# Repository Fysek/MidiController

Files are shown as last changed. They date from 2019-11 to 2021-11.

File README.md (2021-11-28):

# MidiController

The goal of the project is to create and test an extension board with two SIPO 74HC595 shift registers.
The system will work with Arduino Uno.

The registers function is to expand the number of input and output ports of the Arduino board. The whole will work as a controller for the MIDI keyboard.

The use of shift registers allows you to use every available keyboard.

There are two version of the board: 1. Board with additional connections and LED diodes to observe input and outputs
                                    2. Board without connections and LEDs

Tests has been manually executed in NI TestStand. The board was connected via NI myRIO.

## Board without testpoints:

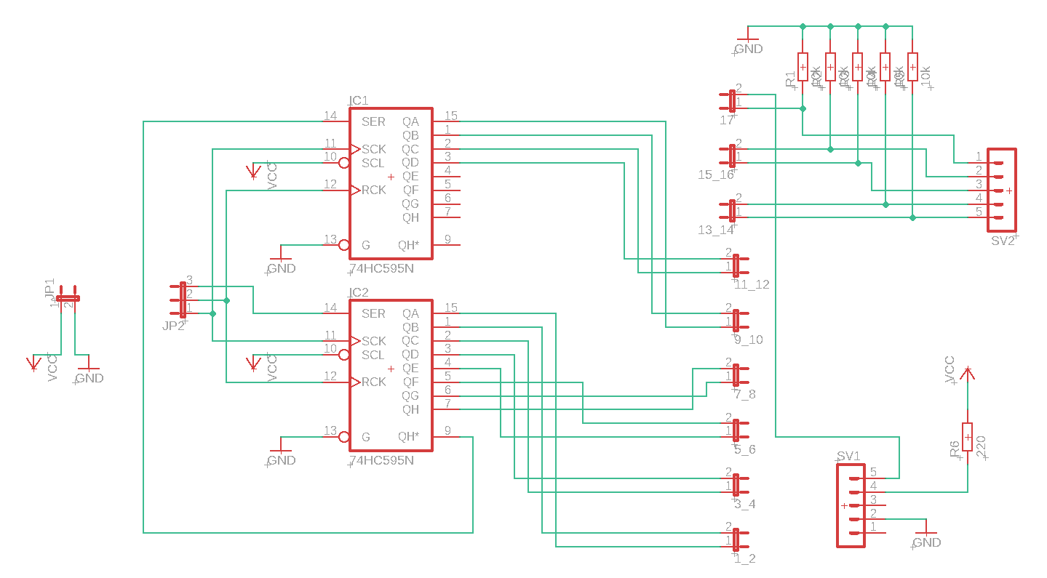
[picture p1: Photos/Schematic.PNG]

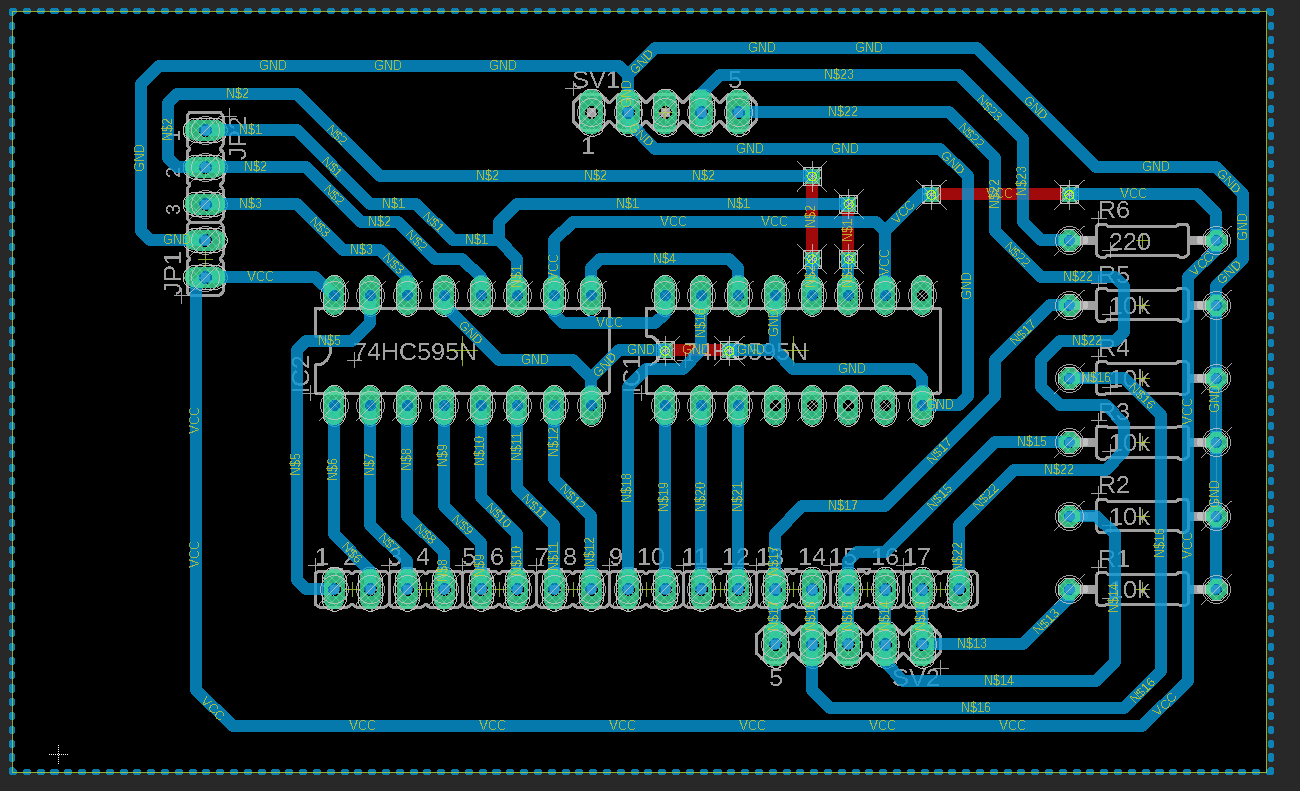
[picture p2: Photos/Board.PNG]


## Board with testpoints:
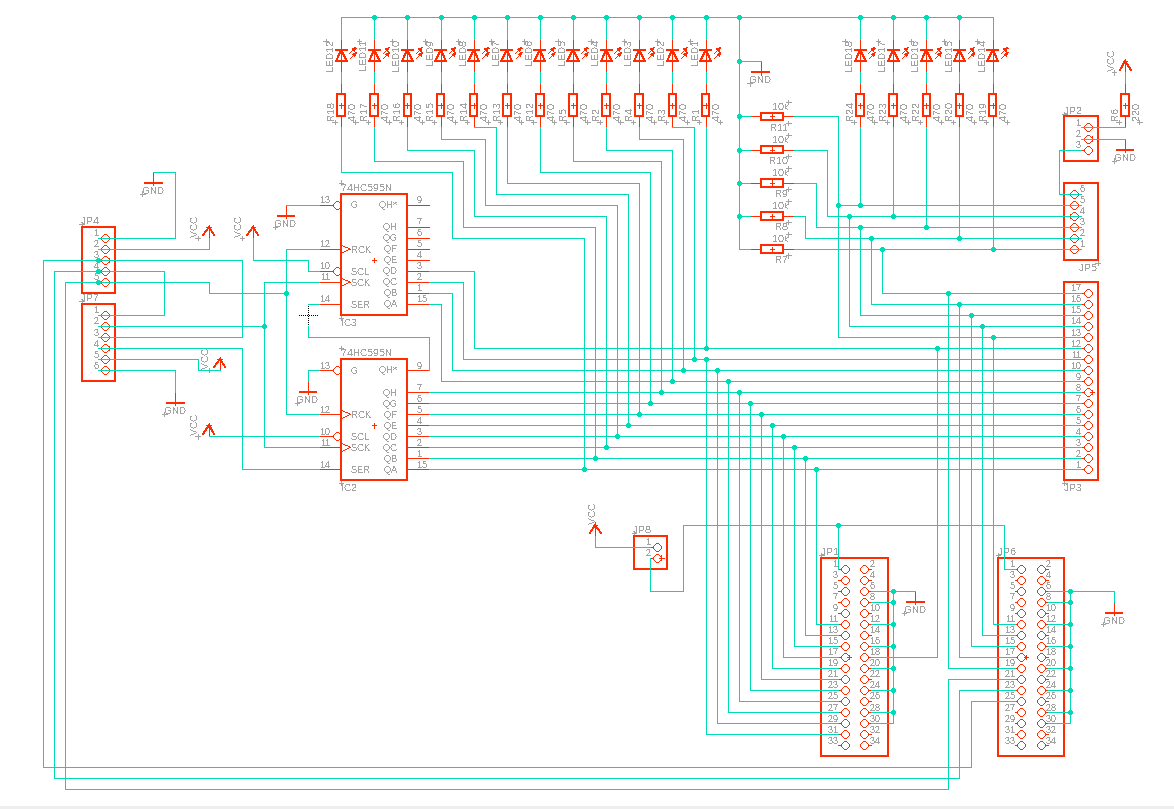
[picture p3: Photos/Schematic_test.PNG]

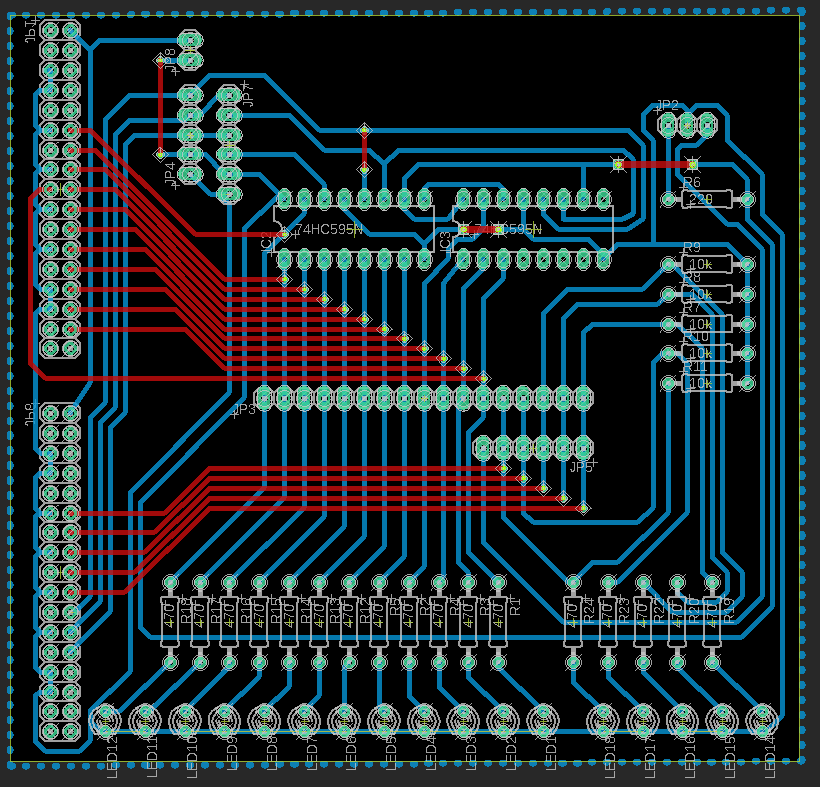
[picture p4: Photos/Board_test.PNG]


## Testing with NI myRIO:
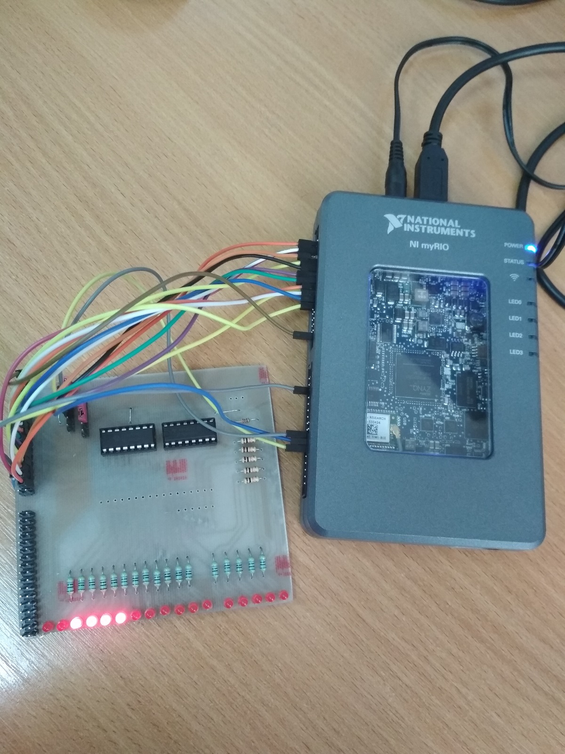
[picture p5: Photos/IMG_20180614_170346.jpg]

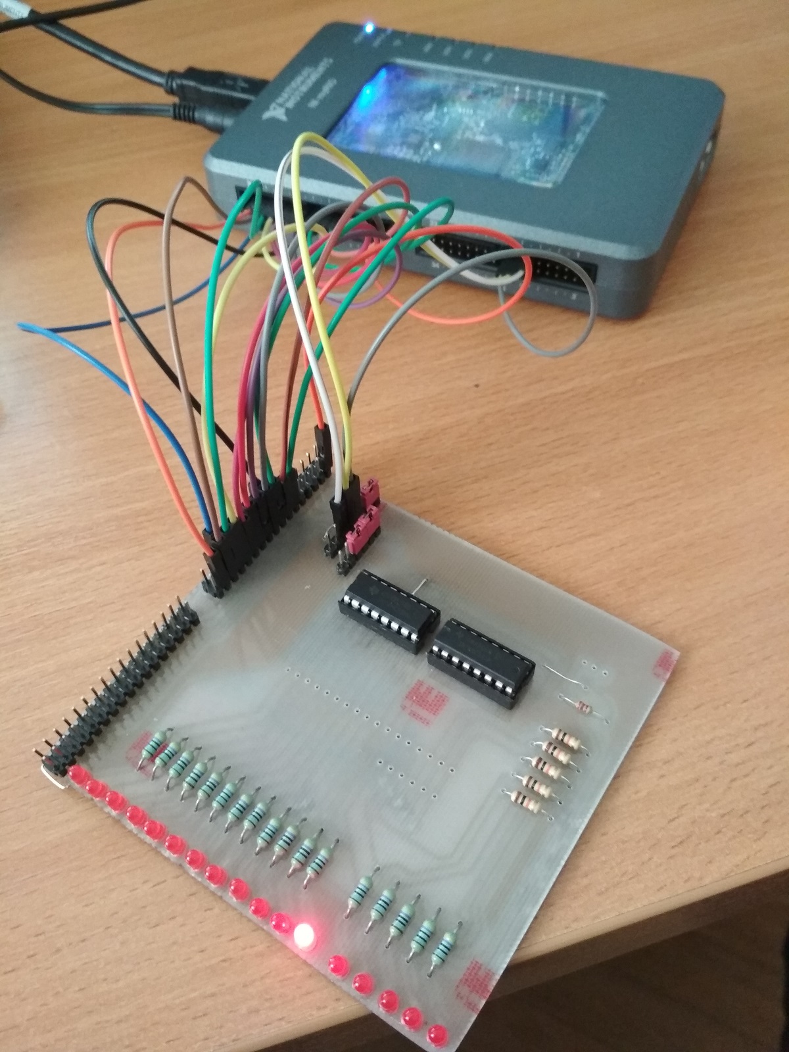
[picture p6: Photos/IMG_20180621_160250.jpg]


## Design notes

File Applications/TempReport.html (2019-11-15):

##### UUT Report

Station ID | PC07
Serial Number | 1
Date | czwartek, 21 czerwca 2018
Time | 16:03:20
Operator | administrator
Execution Time | 50.211 seconds
Number of Results | 24
UUT Result | Passed

Expand/Collapse Expand / Collapse MainSequence

Begin Sequence: MainSequence
(C:\Users\student\Documents\Dyr_Mar\shift_reg\Sequence File 1.seq)

Step | Status | Measurement | Units | Limits
| | | | Nominal Value | Low Limit | High Limit | Comparison Type
Pass/Fail Test | Passed
Parameters
data (B_DIO0 (Pin 11)): | False
latch (B_DIO2 (Pin 15)): | False
clk (B_DIO1 (Pin 13)): | False
TestResults/Data
16bit integer: | 1

Step | Status | Measurement | Units | Limits
| | | | Nominal Value | Low Limit | High Limit | Comparison Type
End(For) | Done

Step | Status | Measurement | Units | Limits
| | | | Nominal Value | Low Limit | High Limit | Comparison Type
Pass/Fail Test | Passed
Parameters
data (B_DIO0 (Pin 11)): | False
latch (B_DIO2 (Pin 15)): | False
clk (B_DIO1 (Pin 13)): | False
TestResults/Data
16bit integer: | 2

Step | Status | Measurement | Units | Limits
| | | | Nominal Value | Low Limit | High Limit | Comparison Type
End(For) | Done

Step | Status | Measurement | Units | Limits
| | | | Nominal Value | Low Limit | High Limit | Comparison Type
Pass/Fail Test | Passed
Parameters
data (B_DIO0 (Pin 11)): | False
latch (B_DIO2 (Pin 15)): | False
clk (B_DIO1 (Pin 13)): | False
TestResults/Data
16bit integer: | 4

Step | Status | Measurement | Units | Limits
| | | | Nominal Value | Low Limit | High Limit | Comparison Type
End(For) | Done

Step | Status | Measurement | Units | Limits
| | | | Nominal Value | Low Limit | High Limit | Comparison Type
Pass/Fail Test | Passed
Parameters
data (B_DIO0 (Pin 11)): | False
latch (B_DIO2 (Pin 15)): | False
clk (B_DIO1 (Pin 13)): | False
TestResults/Data
16bit integer: | 8

Step | Status | Measurement | Units | Limits
| | | | Nominal Value | Low Limit | High Limit | Comparison Type
End(For) | Done

Step | Status | Measurement | Units | Limits
| | | | Nominal Value | Low Limit | High Limit | Comparison Type
Pass/Fail Test | Passed
Parameters
data (B_DIO0 (Pin 11)): | False
latch (B_DIO2 (Pin 15)): | False
clk (B_DIO1 (Pin 13)): | False
TestResults/Data
16bit integer: | 16

Step | Status | Measurement | Units | Limits
| | | | Nominal Value | Low Limit | High Limit | Comparison Type
End(For) | Done

Step | Status | Measurement | Units | Limits
| | | | Nominal Value | Low Limit | High Limit | Comparison Type
Pass/Fail Test | Passed
Parameters
data (B_DIO0 (Pin 11)): | False
latch (B_DIO2 (Pin 15)): | False
clk (B_DIO1 (Pin 13)): | False
TestResults/Data
16bit integer: | 32

Step | Status | Measurement | Units | Limits
| | | | Nominal Value | Low Limit | High Limit | Comparison Type
End(For) | Done

Step | Status | Measurement | Units | Limits
| | | | Nominal Value | Low Limit | High Limit | Comparison Type
Pass/Fail Test | Passed
Parameters
data (B_DIO0 (Pin 11)): | False
latch (B_DIO2 (Pin 15)): | False
clk (B_DIO1 (Pin 13)): | False
TestResults/Data
16bit integer: | 64

Step | Status | Measurement | Units | Limits
| | | | Nominal Value | Low Limit | High Limit | Comparison Type
End(For) | Done

Step | Status | Measurement | Units | Limits
| | | | Nominal Value | Low Limit | High Limit | Comparison Type
Pass/Fail Test | Passed
Parameters
data (B_DIO0 (Pin 11)): | False
latch (B_DIO2 (Pin 15)): | False
clk (B_DIO1 (Pin 13)): | False
TestResults/Data
16bit integer: | 128

Step | Status | Measurement | Units | Limits
| | | | Nominal Value | Low Limit | High Limit | Comparison Type
End(For) | Done

Step | Status | Measurement | Units | Limits
| | | | Nominal Value | Low Limit | High Limit | Comparison Type
Pass/Fail Test | Passed
Parameters
data (B_DIO0 (Pin 11)): | False
latch (B_DIO2 (Pin 15)): | False
clk (B_DIO1 (Pin 13)): | False
TestResults/Data
16bit integer: | 256

Step | Status | Measurement | Units | Limits
| | | | Nominal Value | Low Limit | High Limit | Comparison Type
End(For) | Done

Step | Status | Measurement | Units | Limits
| | | | Nominal Value | Low Limit | High Limit | Comparison Type
Pass/Fail Test | Passed
Parameters
data (B_DIO0 (Pin 11)): | False
latch (B_DIO2 (Pin 15)): | False
clk (B_DIO1 (Pin 13)): | False
TestResults/Data
16bit integer: | 512

Step | Status | Measurement | Units | Limits
| | | | Nominal Value | Low Limit | High Limit | Comparison Type
End(For) | Done

Step | Status | Measurement | Units | Limits
| | | | Nominal Value | Low Limit | High Limit | Comparison Type
Pass/Fail Test | Passed
Parameters
data (B_DIO0 (Pin 11)): | False
latch (B_DIO2 (Pin 15)): | False
clk (B_DIO1 (Pin 13)): | False
TestResults/Data
16bit integer: | 1024

Step | Status | Measurement | Units | Limits
| | | | Nominal Value | Low Limit | High Limit | Comparison Type
End(For) | Done

Step | Status | Measurement | Units | Limits
| | | | Nominal Value | Low Limit | High Limit | Comparison Type
Pass/Fail Test | Passed
Parameters
data (B_DIO0 (Pin 11)): | False
latch (B_DIO2 (Pin 15)): | False
clk (B_DIO1 (Pin 13)): | False
TestResults/Data
16bit integer: | 2048

Step | Status | Measurement | Units | Limits
| | | | Nominal Value | Low Limit | High Limit | Comparison Type
End(For) | Done

End Sequence: MainSequence

##### End UUT Report

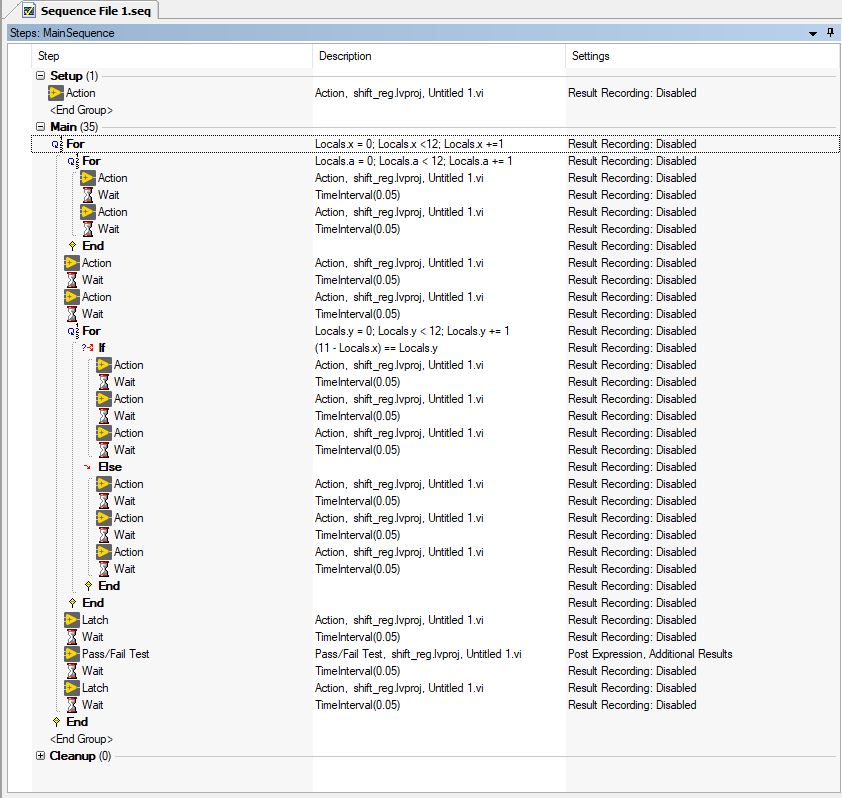
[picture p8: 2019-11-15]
Screen_apps/Sekwencja.JPG

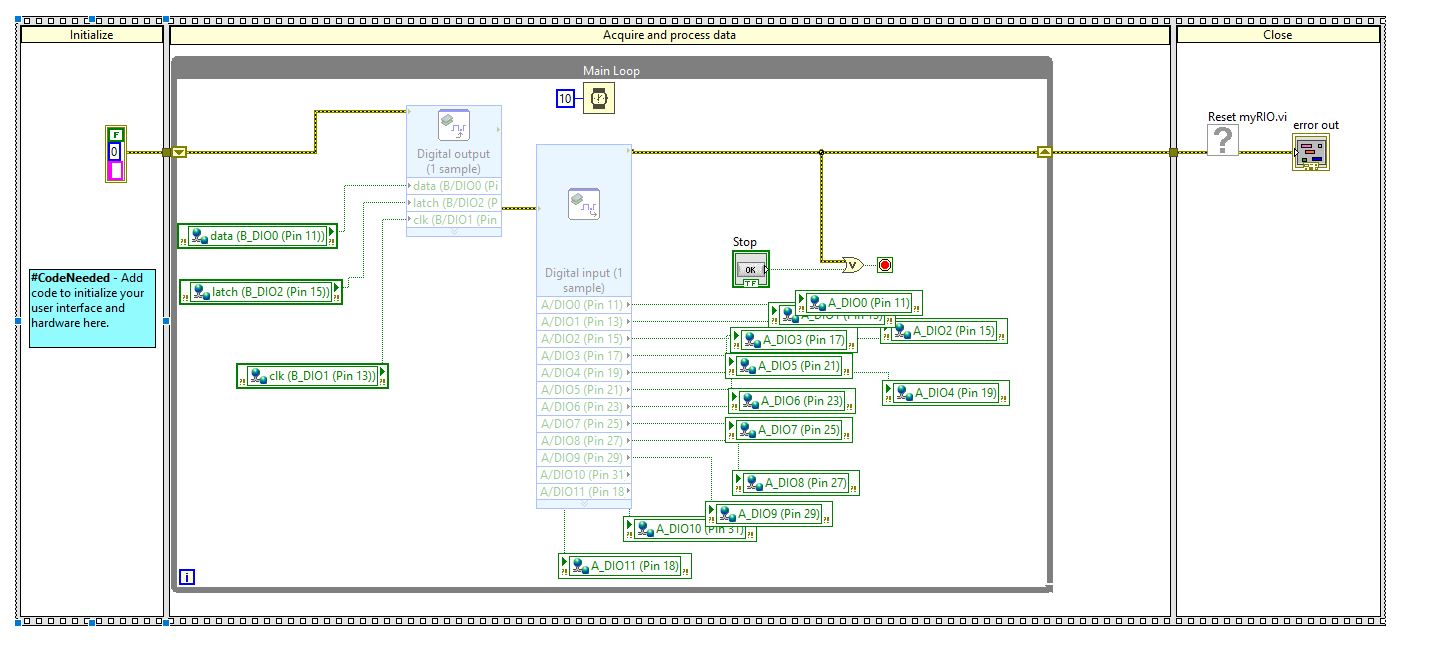
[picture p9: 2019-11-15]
Screen_apps/Main.JPG

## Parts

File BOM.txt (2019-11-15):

Part  Value    Device       Package Description                        
IC2   74HC595N 74HC595N     DIL16   8-bit SHIFT REGISTER, output latch 
IC3   74HC595N 74HC595N     DIL16   8-bit SHIFT REGISTER, output latch 
JP1            PINHD-2X17   2X17    PIN HEADER                         
JP2            PINHD-1X3    1X03    PIN HEADER                         
JP3            PINHD-1X17   1X17    PIN HEADER                         
JP4            PINHD-1X5    1X05    PIN HEADER                         
JP5            PINHD-1X6    1X06    PIN HEADER                         
JP6            PINHD-2X17   2X17    PIN HEADER                         
JP7            PINHD-1X6    1X06    PIN HEADER                         
JP8            PINHD-1X2    1X02    PIN HEADER                         
LED1           LED3MM       LED3MM  LED                                
LED2           LED3MM       LED3MM  LED                                
LED3           LED3MM       LED3MM  LED                                
LED4           LED3MM       LED3MM  LED                                
LED5           LED3MM       LED3MM  LED                                
LED6           LED3MM       LED3MM  LED                                
LED7           LED3MM       LED3MM  LED                                
LED8           LED3MM       LED3MM  LED                                
LED9           LED3MM       LED3MM  LED                                
LED10          LED3MM       LED3MM  LED                                
LED11          LED3MM       LED3MM  LED                                
LED12          LED3MM       LED3MM  LED                                
LED14          LED3MM       LED3MM  LED                                
LED15          LED3MM       LED3MM  LED                                
LED16          LED3MM       LED3MM  LED                                
LED17          LED3MM       LED3MM  LED                                
LED18          LED3MM       LED3MM  LED                                
R1    470      R-EU_0207/10 0207/10 RESISTOR, European symbol          
R2    470      R-EU_0207/10 0207/10 RESISTOR, European symbol          
R3    470      R-EU_0207/10 0207/10 RESISTOR, European symbol          
R4    470      R-EU_0207/10 0207/10 RESISTOR, European symbol          
R5    470      R-EU_0207/10 0207/10 RESISTOR, European symbol          
R6    220      R-EU_0207/10 0207/10 RESISTOR, European symbol          
R7    10k      R-EU_0207/10 0207/10 RESISTOR, European symbol          
R8    10k      R-EU_0207/10 0207/10 RESISTOR, European symbol          
R9    10k      R-EU_0207/10 0207/10 RESISTOR, European symbol          
R10   10k      R-EU_0207/10 0207/10 RESISTOR, European symbol          
R11   10k      R-EU_0207/10 0207/10 RESISTOR, European symbol          
R12   470      R-EU_0207/10 0207/10 RESISTOR, European symbol          
R13   470      R-EU_0207/10 0207/10 RESISTOR, European symbol          
R14   470      R-EU_0207/10 0207/10 RESISTOR, European symbol          
R15   470      R-EU_0207/10 0207/10 RESISTOR, European symbol          
R16   470      R-EU_0207/10 0207/10 RESISTOR, European symbol          
R17   470      R-EU_0207/10 0207/10 RESISTOR, European symbol          
R18   470      R-EU_0207/10 0207/10 RESISTOR, European symbol          
R19   470      R-EU_0207/10 0207/10 RESISTOR, European symbol          
R20   470      R-EU_0207/10 0207/10 RESISTOR, European symbol          
R22   470      R-EU_0207/10 0207/10 RESISTOR, European symbol          
R23   470      R-EU_0207/10 0207/10 RESISTOR, European symbol          
R24   470      R-EU_0207/10 0207/10 RESISTOR, European symbol

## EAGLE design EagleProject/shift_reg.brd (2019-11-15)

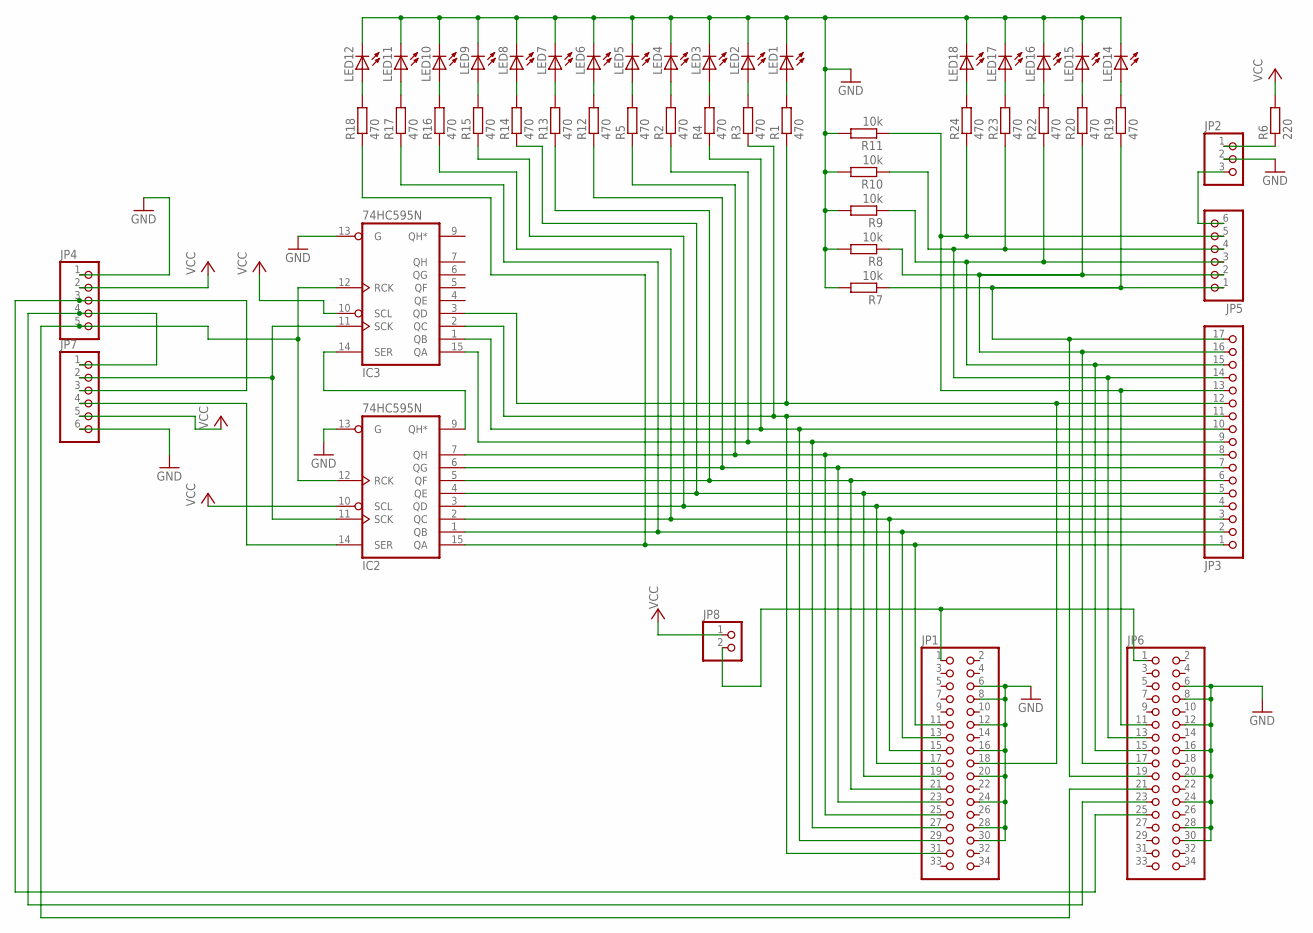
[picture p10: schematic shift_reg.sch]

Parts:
IC2, IC3: 74HC595N; DIL16
JP1, JP6: PINHD-2X17; 2X17
JP2: PINHD-1X3; 1X03
JP3: PINHD-1X17; 1X17
JP4: PINHD-1X5; 1X05
JP5, JP7: PINHD-1X6; 1X06
JP8: PINHD-1X2; 1X02
LED1, LED2, LED3, LED4, LED5, LED6, LED7, LED8, LED9, LED10, LED11, LED12, LED14, LED15, LED16, LED17, LED18: LED3MM
R1, R2, R3, R4, R5, R12, R13, R14, R15, R16, R17, R18, R19, R20, R22, R23, R24: 470; 0207/10
R6: 220; 0207/10
R7, R8, R9, R10, R11: 10k; 0207/10

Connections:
GND: IC2.8 (GND), IC2.13 (G), IC3.8 (GND), IC3.13 (G), JP1.6, JP1.8, JP1.12, JP1.16, JP1.20, JP1.24, JP1.28, JP1.30, JP2.2, JP4.1, JP6.6, JP6.8, JP6.12, JP6.16, JP6.20, JP6.24, JP6.28, JP6.30, JP7.6, LED1.K (C), LED2.K (C), LED3.K (C), LED4.K (C), LED5.K (C), LED6.K (C), LED7.K (C), LED8.K (C), LED9.K (C), LED10.K (C), LED11.K (C), LED12.K (C), LED14.K (C), LED15.K (C), LED16.K (C), LED17.K (C), LED18.K (C), R7.2, R8.2, R9.2, R10.2, R11.2
unnamed: JP3.13, JP5.5, JP6.11, R11.1, R24.1
unnamed: JP2.3, JP5.6
unnamed: JP3.15, JP5.3, JP6.15, R9.1, R22.1
unnamed: LED1.A, R1.2
unnamed: JP1.1, JP6.1, JP8.2
unnamed: IC2.12 (RCK), IC3.12 (RCK), JP4.5, JP6.21
unnamed: IC2.7 (QH), JP1.25, JP3.8, R5.1
unnamed: IC3.15 (QA), JP1.27, JP3.9, R2.1
unnamed: IC2.9 (QH*), IC3.14 (SER)
unnamed: IC2.14 (SER), JP7.4
unnamed: JP3.16, JP5.2, JP6.17, R8.1, R20.1
unnamed: JP2.1, R6.1
unnamed: IC2.5 (QF), JP1.21, JP3.6, R13.1
unnamed: JP3.17, JP5.1, JP6.19, R7.1, R19.1
unnamed: LED2.A, R3.2
unnamed: LED3.A, R4.2
unnamed: JP3.14, JP5.4, JP6.13, R10.1, R23.1
unnamed: LED4.A, R2.2
unnamed: LED5.A, R5.2
unnamed: LED9.A, R15.2
unnamed: LED8.A, R14.2
unnamed: IC3.1 (QB), JP1.29, JP3.10, R4.1
unnamed: IC3.2 (QC), JP1.31, JP3.11, R3.1
unnamed: IC3.3 (QD), JP1.18, JP3.12, R1.1
unnamed: LED7.A, R13.2
unnamed: LED6.A, R12.2
unnamed: LED10.A, R16.2
unnamed: LED11.A, R17.2
unnamed: LED12.A, R18.2
unnamed: JP4.3, JP6.25, JP7.3
unnamed: JP4.4, JP6.23, JP7.1
unnamed: IC2.11 (SCK), IC3.11 (SCK), JP7.2
unnamed: IC2.1 (QB), JP1.13, JP3.2, R17.1
unnamed: IC2.6 (QG), JP1.23, JP3.7, R12.1
unnamed: IC2.15 (QA), JP1.11, JP3.1, R18.1
unnamed: LED14.A, R19.2
unnamed: LED15.A, R20.2
unnamed: LED16.A, R22.2
unnamed: LED17.A, R23.2
unnamed: LED18.A, R24.2
unnamed: IC2.2 (QC), JP1.15, JP3.3, R16.1
unnamed: IC2.4 (QE), JP1.19, JP3.5, R14.1
unnamed: IC2.3 (QD), JP1.17, JP3.4, R15.1
VCC: IC2.10 (SCL), IC2.16 (VCC), IC3.10 (SCL), IC3.16 (VCC), JP4.2, JP7.5, JP8.1, R6.2

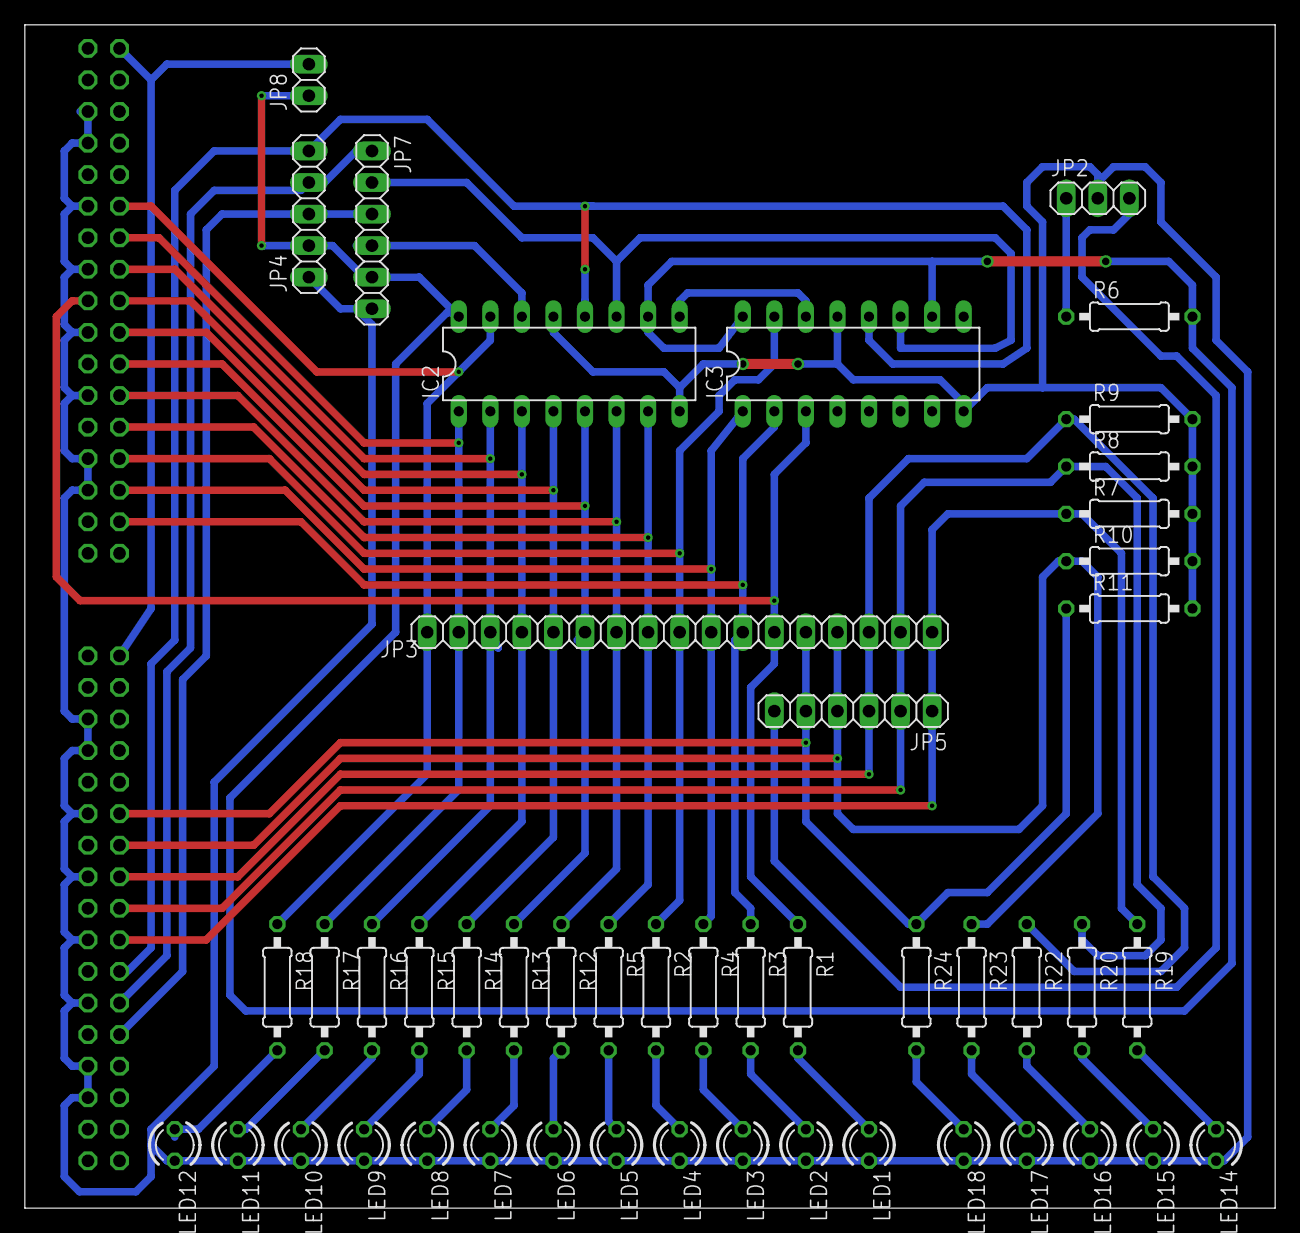
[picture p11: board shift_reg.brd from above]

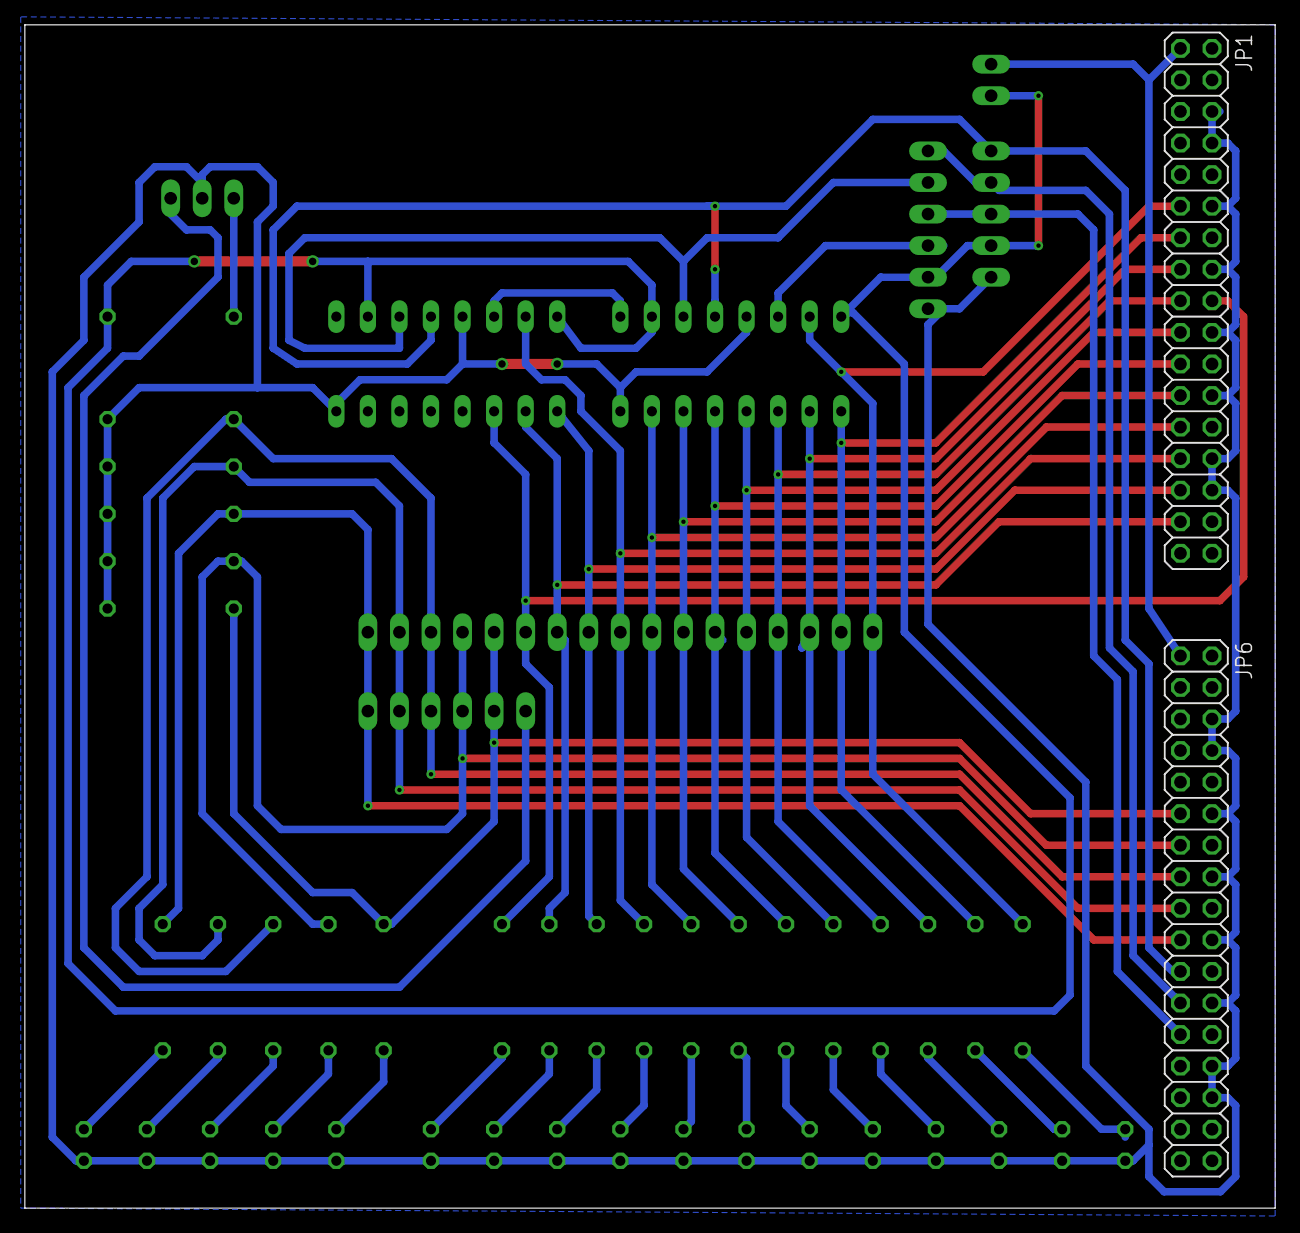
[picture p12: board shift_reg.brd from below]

Board: 2 copper layers, 100.6 x 95.2 mm, 50 parts (2 on the bottom side), 45 nets.

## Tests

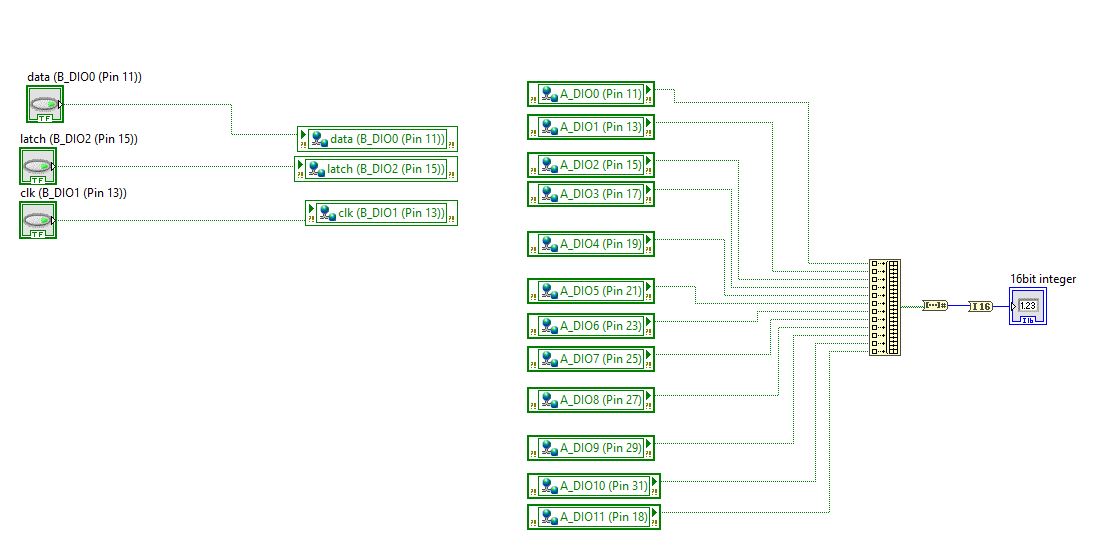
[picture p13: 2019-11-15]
Screen_apps/Teststand_in_out.JPG

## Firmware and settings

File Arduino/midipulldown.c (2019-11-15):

#define NUM_ROWS 5
#define NUM_COLS 12

#define NOTE_ON_CMD 0x90
#define NOTE_OFF_CMD 0x80
#define NOTE_VELOCITY 127

//MIDI baud rate
#define SERIAL_RATE 31250

// Pin Definitions

// Row input pins
const int row1Pin = 2;
const int row2Pin = 3;
const int row3Pin = 4;
const int row4Pin = 5;
const int row5Pin = 6;


// 74HC595 pins
const int dataPin = 8;
const int latchPin = 9;
const int clockPin = 10;

boolean keyPressed[NUM_ROWS][NUM_COLS];
uint8_t keyToMidiMap[NUM_ROWS][NUM_COLS];

// bitmasks for scanning columns
int bits[] =
{ 
  B00000001,
  B00000010,
  B00000100,
  B00001000,
  B00010000,
  B00100000,
  B01000000,
  B10000000
};

void setup()
{
  int note = 31;

  for(int colCtr = 0; colCtr < NUM_COLS; ++colCtr)
  {
    for(int rowCtr = 0; rowCtr < NUM_ROWS; ++rowCtr)
    {
      keyPressed[rowCtr][colCtr] = false;
      keyToMidiMap[rowCtr][colCtr] = note;
      note++;
    }
  }

  // setup pins output/input mode
  pinMode(dataPin, OUTPUT);
  pinMode(clockPin, OUTPUT);
  pinMode(latchPin, OUTPUT);

  pinMode(row1Pin, INPUT);
  pinMode(row2Pin, INPUT);
  pinMode(row3Pin, INPUT);
  pinMode(row4Pin, INPUT);
  pinMode(row5Pin, INPUT);

  Serial.begin(SERIAL_RATE);
}

void loop()
{
  for (int colCtr = 0; colCtr < NUM_COLS; ++colCtr)
  {
    //scan next column
    scanColumn(colCtr);

    //get row values at this column
    int rowValue[NUM_ROWS];
    rowValue[0] = digitalRead(row1Pin);
    rowValue[1] = digitalRead(row2Pin);
    rowValue[2] = digitalRead(row3Pin);
    rowValue[3] = digitalRead(row4Pin);
    rowValue[4] = digitalRead(row5Pin);


    // process keys pressed
    for(int rowCtr=0; rowCtr<NUM_ROWS; ++rowCtr)
    {
      if(rowValue[rowCtr] != 0 && !keyPressed[rowCtr][colCtr])
      {
        keyPressed[rowCtr][colCtr] = true;
        noteOn(rowCtr,colCtr);
      }
    }

    // process keys released
    for(int rowCtr=0; rowCtr<NUM_ROWS; ++rowCtr)
    {
      if(rowValue[rowCtr] == 0 && keyPressed[rowCtr][colCtr])
      {
        keyPressed[rowCtr][colCtr] = false;
        noteOff(rowCtr,colCtr);
      }
    }
  }
}

void scanColumn(int colNum)   
{
  digitalWrite(latchPin, LOW);

  if(0 <= colNum && colNum <= 7)
  {
    shiftOut(dataPin, clockPin, MSBFIRST, B00000000); //right sr
    shiftOut(dataPin, clockPin, MSBFIRST, bits[colNum]); //left sr
  }
  else
  {
    shiftOut(dataPin, clockPin, MSBFIRST, bits[colNum-8]); //right sr
    shiftOut(dataPin, clockPin, MSBFIRST, B00000000); //left sr
  }
  digitalWrite(latchPin, HIGH);
}

void noteOn(int row, int col)
{
  Serial.write(NOTE_ON_CMD);
  Serial.write(keyToMidiMap[row][col]);
  Serial.write(NOTE_VELOCITY);
}

void noteOff(int row, int col)
{
  Serial.write(NOTE_OFF_CMD);
  Serial.write(keyToMidiMap[row][col]);
  Serial.write(NOTE_VELOCITY);
}
